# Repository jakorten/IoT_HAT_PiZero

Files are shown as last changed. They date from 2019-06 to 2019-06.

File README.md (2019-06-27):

# IoT HAT for Pi Zero

Leuk zo'n Raspberry Pi Zero van i&i, maar hoe doe je er nu IoT mee?!
- optie A: USB hub of zo, dan een Ethernet of WiFi dongle
- optie B: Weggooien en vervangen door een Raspberry Pi Zero W, maar ja zonde, gemiste kans!
- optie C: Gewoon een IoT HAT er op plaatsen!

LoRa, ZigBee, WiFi, Bluetooth Low Energy?
Eigenlijk wilde ik het zo universeel mogelijk maken, door er een XBee header op te plaatsen kun je gewoon kiezen welke module je wilt gebruiken.

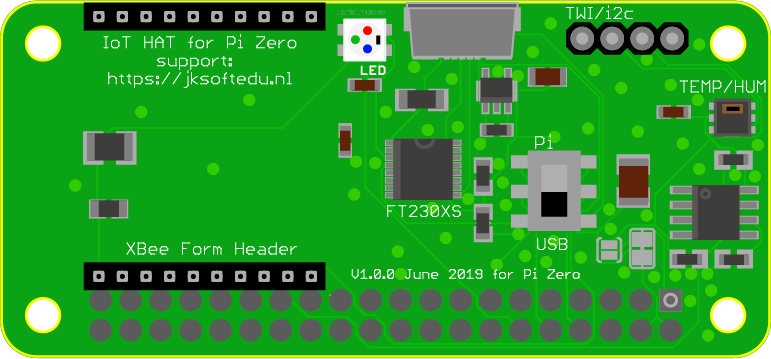
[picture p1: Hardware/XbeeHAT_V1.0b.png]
IoT Hat for Pi Image


N.b. Deze HAT werd geïnspireerd door: https://sixfab.com/product/xbee-shield/ welke is al meer uit ontwikkeld / te koop is.

### Over die HAT
Die originele HAT is in feite een https://www.sparkfun.com/products/11812 maar dan in HAT vorm.
Dat is mooi, maar ik heb gewoon een voorraad van die XBee Explorers liggen en wil er toch geen échte XBee's mee programmeren.

### Mijn versie:
- Het idee van direct met USB verbinden met de XBee module leek me echter wel een goed idee dus ik heb de selectie Pi/USB wel aangehouden.
- Er zit ook een NeoPixel LED op de HAT die je vanaf je Pi aan kunt sturen.
- Daarnaast een Vochtigheids/Temperatuur sensor via i2c én een i2c header voor evt andere sensor.
- Een flash geheugen chip want anders mag het geen HAT genoemd worden.

N.b. Dit is natuurlijk eerste versie dus ws. moet ik er nog aan sleutelen en het zal even duren voor ik de printjes van deze versie uit China binnen heb en gesoldeerd heb. Laat gerust weten als je interesse hebt. Dit is niet mijn eerste HAT die ik maak, ik heb o.a. weerstation HAT's, aansturingen voor tuinberegening, etc. daarnaast 'uiteraard' voor mijn reanimatie simulator.

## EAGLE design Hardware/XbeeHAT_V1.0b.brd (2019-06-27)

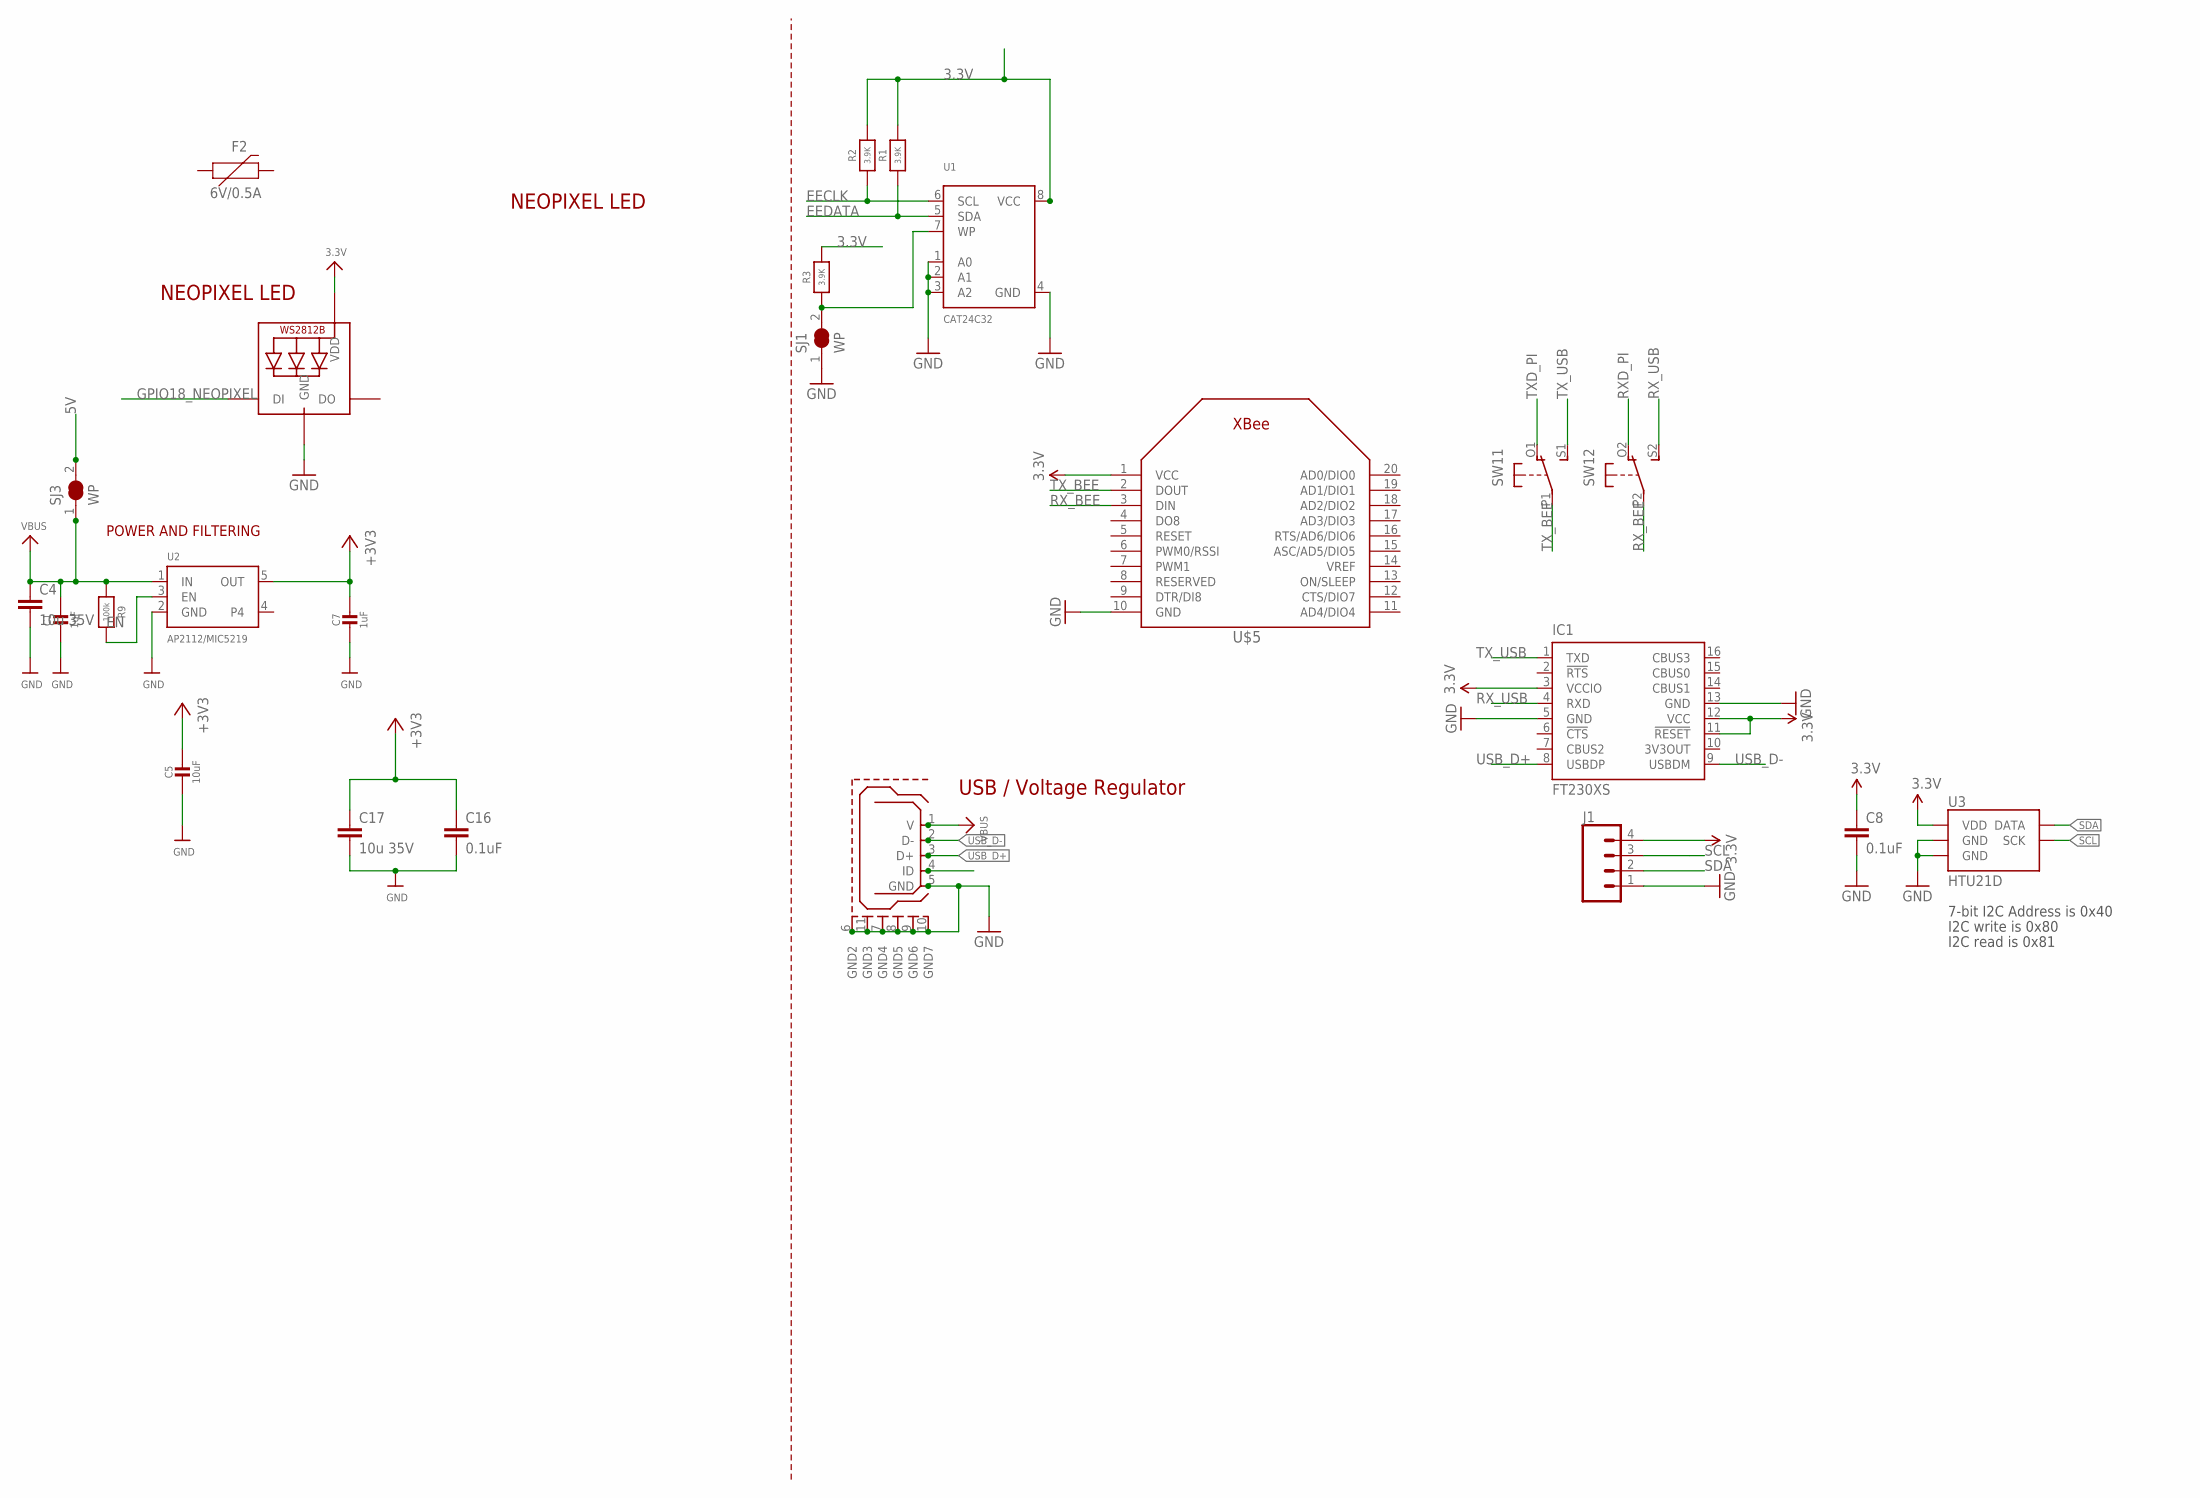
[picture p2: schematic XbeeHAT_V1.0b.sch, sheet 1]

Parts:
798-ZX62-B-5PA1: USB_MICROB; USB_MICROB_PACKAGE
C1, C7: 1uF; 0603-NO
C4, C17: 10u 35V; C1210
C5: 10uF; 0805-NO
C8: 0.1uF; 0603-CAP
C16: 0.1uF; C0805
F2: 6V/0.5A; 1206
IC1: FT230XS; SSOP16
J1: CONN_04; 1X04
LED: WS2812B3535; LED3535
R1, R2, R3: 3.9K; 0805-NO@1
R9: 100k; 0603-NO@1
SJ1, SJ3: WP; SOLDERJUMPER_CLOSEDWIRE
SW1: DPDT-EG1390; EG1390
U1: CAT24C32; SOIC8_150MIL
U2: AP2112/MIC5219; SOT23-5
U3: HTU21D
U$5: XBEE

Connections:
3.3V: C5.1, C7.1, C8.1, C16.1, C17.1, IC1.3 (VCCIO), IC1.11 (!RESET), IC1.12 (VCC), LED.2 (VDD), R1.2, R2.2, R3.2, U1.8 (VCC), U2.5 (OUT), U3.VDD, U$5.1 (VCC); also elsewhere on the board
5V: SJ3.2; also elsewhere on the board
EECLK: R2.1, U1.6 (SCL)
EEDATA: R1.1, U1.5 (SDA); also elsewhere on the board
EN: R9.2, U2.3 (EN)
GND: 798-ZX62-B-5PA1.5 (GND), 798-ZX62-B-5PA1.6 (GND2), 798-ZX62-B-5PA1.7 (GND4), 798-ZX62-B-5PA1.8 (GND5), 798-ZX62-B-5PA1.9 (GND6), 798-ZX62-B-5PA1.10 (GND7), 798-ZX62-B-5PA1.11 (GND3), C1.2, C4.2, C5.2, C7.2, C8.2, C16.2, C17.2, IC1.5 (GND), IC1.13 (GND), J1.1, LED.4 (GND), SJ1.1, U1.1 (A0), U1.2 (A1), U1.3 (A2), U1.4 (GND), U2.2 (GND), U3.7 (GND), U3.GND, U$5.10 (GND); also elsewhere on the board
GPIO18_NEOPIXEL: LED.1 (DI); also elsewhere on the board
unnamed: R3.1, SJ1.2, U1.7 (WP)
RXD_PI: SW1.O2 (O); also elsewhere on the board
RX_BEE: SW1.P2, U$5.3 (DIN)
RX_USB: IC1.4 (RXD), SW1.S2 (S)
SCL: J1.3, U3.SCK; also elsewhere on the board
SDA: J1.2, U3.DATA; also elsewhere on the board
TXD_PI: SW1.O1 (O); also elsewhere on the board
TX_BEE: SW1.P1, U$5.2 (DOUT)
TX_USB: IC1.1 (TXD), SW1.S1 (S)
USB_D+: 798-ZX62-B-5PA1.3 (D+), IC1.8 (USBDP)
USB_D-: 798-ZX62-B-5PA1.2 (D-), IC1.9 (USBDM)
VBUS: 798-ZX62-B-5PA1.1 (V), C1.1, C4.1, R9.1, SJ3.1, U2.1 (IN)
VCC: J1.4

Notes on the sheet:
POWER AND FILTERING
USB / Voltage Regulator
NEOPIXEL LED
7-bit I2C Address is 0x40
I2C write is 0x80
I2C read is 0x81

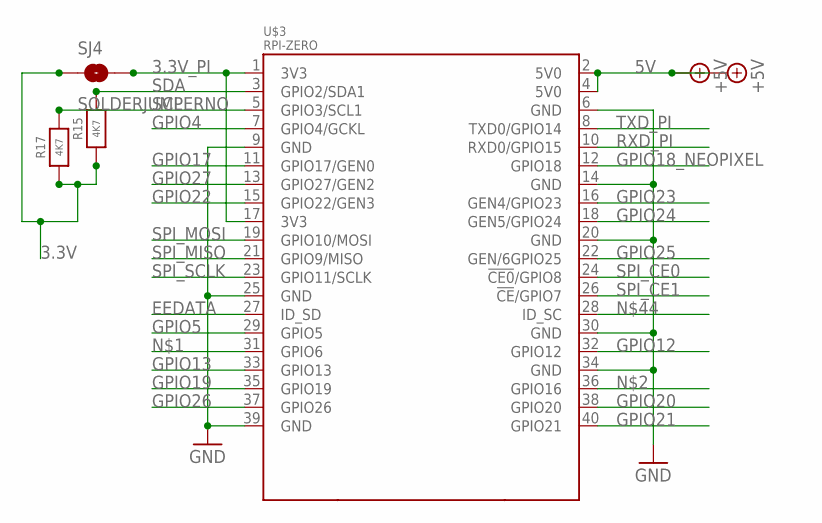
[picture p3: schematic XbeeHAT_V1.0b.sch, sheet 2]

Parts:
R15, R17: 4K7; 0805-NO@1
SJ4: SOLDERJUMPERNO; SJ_2S-NO
U$3: RPI-ZERO; RASPBERRYPI_BASTELSTUBE_V13_RASPI_BOARD_B+_FULL

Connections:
3.3V: R15.1, R17.1, SJ4.1; also elsewhere on the board
3.3V_PI: SJ4.2, U$3.1 (3V3), U$3.17 (3V3)
5V: U$3.2 (5V0), U$3.4 (5V0); also elsewhere on the board
EEDATA: U$3.27 (ID_SD); also elsewhere on the board
GND: U$3.6 (GND), U$3.9 (GND), U$3.14 (GND), U$3.20 (GND), U$3.25 (GND), U$3.30 (GND), U$3.34 (GND), U$3.39 (GND); also elsewhere on the board
GPIO4: U$3.7 (GPIO4/GCKL)
GPIO5: U$3.29 (GPIO5)
GPIO12: U$3.32 (GPIO12)
GPIO13: U$3.33 (GPIO13)
GPIO17: U$3.11 (GPIO17/GEN0)
GPIO18_NEOPIXEL: U$3.12 (GPIO18); also elsewhere on the board
GPIO19: U$3.35 (GPIO19)
GPIO20: U$3.38 (GPIO20)
GPIO21: U$3.40 (GPIO21)
GPIO22: U$3.15 (GPIO22/GEN3)
GPIO23: U$3.16 (GEN4/GPIO23)
GPIO24: U$3.18 (GEN5/GPIO24)
GPIO25: U$3.22 (GEN/6GPIO25)
GPIO26: U$3.37 (GPIO26)
GPIO27: U$3.13 (GPIO27/GEN2)
RXD_PI: U$3.10 (RXD0/GPIO15); also elsewhere on the board
SCL: R17.2, U$3.5 (GPIO3/SCL1); also elsewhere on the board
SDA: R15.2, U$3.3 (GPIO2/SDA1); also elsewhere on the board
SPI_CE0: U$3.24 (!CE0!/GPIO8)
SPI_CE1: U$3.26 (!CE!/GPIO7)
SPI_MISO: U$3.21 (GPIO9/MISO)
SPI_MOSI: U$3.19 (GPIO10/MOSI)
SPI_SCLK: U$3.23 (GPIO11/SCLK)
TXD_PI: U$3.8 (TXD0/GPIO14); also elsewhere on the board

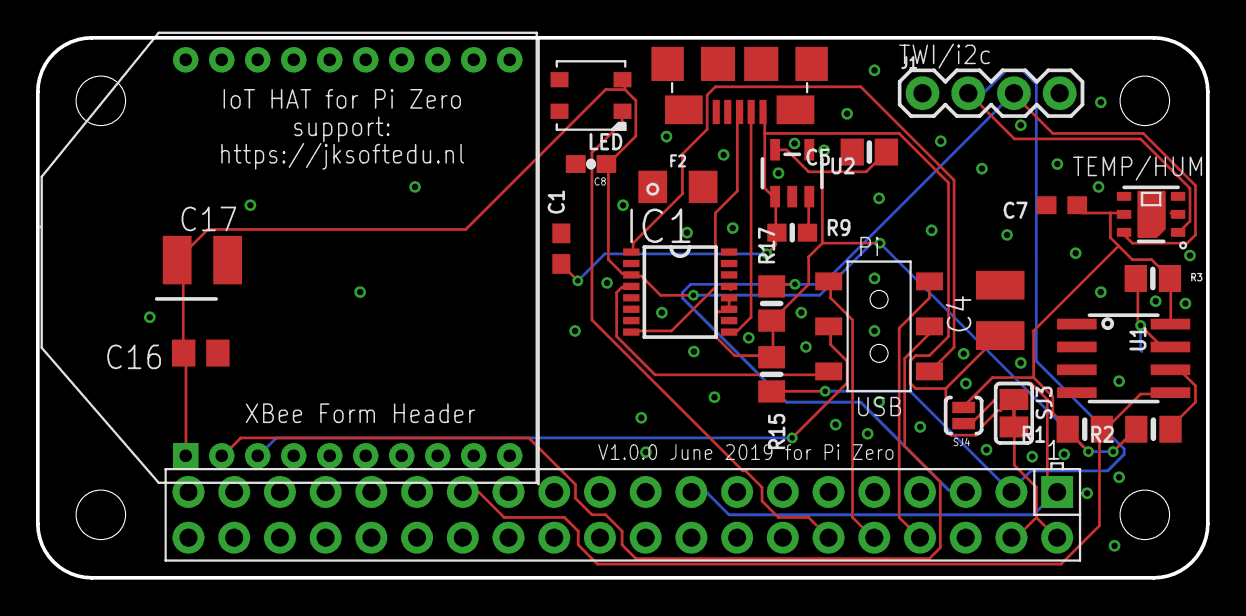
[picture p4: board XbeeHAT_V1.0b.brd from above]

Board: 2 copper layers, 65.0 x 30.0 mm, 27 parts (1 on the bottom side), 20 nets.

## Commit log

2019-06-27 Hardware files
    Hardware files (eagle / gerber)
    [XbeeHAT_V1.0b.brd, XbeeHAT_V1.0b.sch]
2019-06-27 Updated Images PCB
    Updated Images PCB

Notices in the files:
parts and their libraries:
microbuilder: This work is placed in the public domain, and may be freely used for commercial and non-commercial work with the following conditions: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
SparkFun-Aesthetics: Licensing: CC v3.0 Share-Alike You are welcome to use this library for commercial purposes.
